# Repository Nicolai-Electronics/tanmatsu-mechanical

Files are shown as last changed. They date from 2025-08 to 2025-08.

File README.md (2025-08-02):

# Tanmatsu mechanical design files

This repository contains the design files for the 3D printed mechanical parts for the Tanmatsu.

These consist of the following: 
  * Case
  * Spacer 
  * Speaker adapter 

All parts are integrated in the FreeCAD design file. Also a separate
STEP file each part, so people can print these directly from this
repository.

In order to add the bolts to the design, install the 'Fasteners' workbench 
via the add-on manager. 

# Which revision do I need?

You can find out your mainboard revision by going to `Settings > Device
information` in the launcher firmware.

If you have board revision 1 or 2 you need the "for revision 2" files. If you
have a newer board revision you need the "for revision 3" files.

The breaking change in case design is due to us having to move the audio jack
down by two millimeters and outwards by two millimeters to solve a
manufacturing problem.

# Getting Tanmatsu STEP files.

Clone the repositories for both the Tanmatsu mainboard and a frontpanel. 

 * Open the design wiht KiCAD.
 * Open the PCB editor.
 * Select Export -> "STEP / GLB/, etc."
 * Select STEP as format. 
 * Use the default settings
 * Press Export. 
 * Now import the STEP files in the FreeCAD file. Make sure to disable the
   'Linkgroup' setting while importing. Otherwise deleting the PCB will become
   very tiresome. 
 * Place them in the correct location by selecting the corresponding PCB and:
    * Tanmatsu PCB: set Data -> Placement -> Position -> z = -1.55 mm
    * Frontpanel PCB: set Data -> Placement -> Position -> z = 2.40 mm

# Generating output files

Generating the output files from FreeCAD happens via a bash script command line
form. With FreeCAD close and from the repository root directory execute
`./tools/export_manufacturing_files.sh`. The resulting STEP and AMF files will 
appear in the `./release/` directory with the correct names. 

The 'tools' directory has a simple FreeCAD file available for testing purposes.
Exporting everything while debugging Python scripts get boring real fast.

Note: The script does produce some errors from the Fasteners Workbench. 
See this issue: https://github.com/shaise/FreeCAD_FastenersWB/issues/454

# License

Copyright 2024-2025 Nicolai Electronics

Copyright 2024-2025 Ytec Engineering

Copyright 2025 Jelle Haandrikman

This work is licensed under the CERN-OHL-P license. Full license text is
included in the [LICENSE](LICENSE) file.

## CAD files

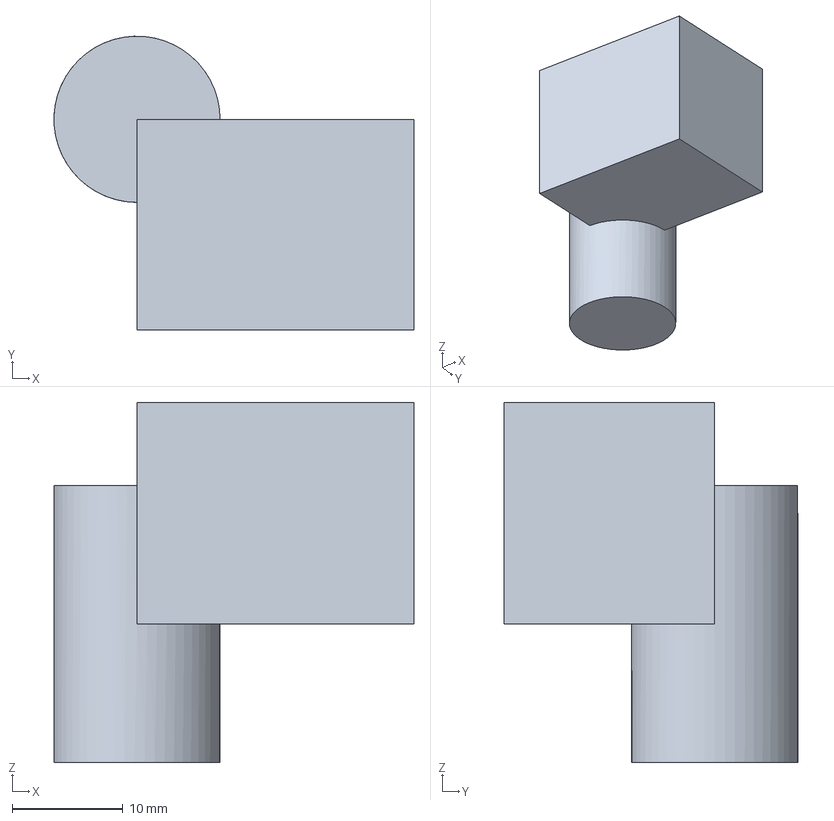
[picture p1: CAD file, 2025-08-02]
tools/test_freecad_file.FCStd
32.5 x 26.5 x 32.5 mm

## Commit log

2025-05-04 Remove overhanging catch for battery box, rename STL files
    [assembly.scad, assembly_internal_antenna.stl, assembly_nosma.stl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]
2025-06-12 First setup with FreeCAD design files.
    [Tanmatsu_3D-printed-case.step, Tanmatsu_3D-printed-spacer.step, assembly_internal_antenna.stl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]
2025-06-12 Getting everything set up.
    * Updated README.md with info on how to get STEP files from PCB.
    * Added STEP files from frontpanel and Tanmatsu mainboard.
    * Tanmatsu mainboard now has the USB-A connector.
2025-06-12 FreeCAD model for speaker_adapter added.
    [speaker_adapter-speaker_adapter.step, speaker_adapter.FCStd]
2025-06-12 Case: added studs near screw holes.
    [Tanmatsu_3D-printed-case.step, speaker_adapter.FCStd]
2025-06-12 Speaker now has correct length and added AMF files.
    [Tanmatsu_3D-printed-case.amf, Tanmatsu_3D-printed-spacer.amf, speaker_adapter-speaker_adapter.amf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]
2025-06-12 Case has connectors and speaker adapter included
    Case now has room for all external connectors
    SNAFU with asymetrical mounting holes fixed.
    Speaker adapter now included.
    Keycord holes now more robust extruded.
    [Tanmatsu_3D-printed-case.amf, Tanmatsu_3D-printed-case.step, speaker_adapter.FCStd]
2025-06-12 Fix changes from yesterday evening.
    Added original STL assembly for easier comparing sizes.
    Made battery compartment less tall and now doesn't bump into diodes.
    Notches for holding PCB at upper side now also have clearance for PCB.
    [Tanmatsu_3D-printed-case.amf, Tanmatsu_3D-printed-case.step, Tanmatsu_3D-printed-speaker_adapter.amf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]
2025-06-12 Small changes for ergonomics and older tanmatsu mic location.
    [Tanmatsu_3D-printed-case.amf, Tanmatsu_3D-printed-case_field_test.amf]
2025-06-12 Increased wall thickness for ergonomics for real.
    [Tanmatsu_3D-printed-case.amf, Tanmatsu_3D-printed-case_field_test.amf]
2025-06-12 Chamfers, fillets and thingies OK now.
    [Tanmatsu_3D-printed-case.amf, Tanmatsu_3D-printed-case_field_test.amf]
2025-06-12 Proto version for production
    Refactored Case build-up
    Speaker case size the same as speaker adapter
    Lower edges to 24 mm.
    Audio connector protection attached to case and spacer.
    Edges have now fillets
    [Tanmatsu_3D-printed-case.amf, Tanmatsu_3D-printed-case.step, Tanmatsu_3D-printed-case_field_test.amf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]
2025-06-12 Remove separate speaker adapter design file.
    [speaker_adapter-speaker_adapter.amf, speaker_adapter-speaker_adapter.step, speaker_adapter.FCStd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]
2025-06-12 Solved review comments according to 'issues.txt'.
    [Tanmatsu_3D-printed-case.amf, Tanmatsu_3D-printed-case.step, Tanmatsu_3D-printed-spacer.amf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]
2025-06-12 First Of A kind Updates to Case and Spacer
    Audio connector protection has more space for audio connnector.
    Audio connector protection better fit.
    Ergonic grip now has better fit, renders and mirror now works.
    CATT connector has ridges on case and spacer.
    Refactored dependencies for keyholes.
    Spacer for field test models added.
    [Tanmatsu_3D-printed-case.amf, Tanmatsu_3D-printed-case.step, Tanmatsu_3D-printed-case_field_test.amf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]
2025-06-12 Field Test adapter and spacer now fit nicely around audio connector.
    Removed issues file with review input from Renze.
    Coordinates of field test case now in line with original case.
    [Tanmatsu_3D-printed-case_field_test.amf, Tanmatsu_3D-printed-case_field_test.step, Tanmatsu_3D-printed-spacer_field_test.amf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]
2025-06-12 New audio protector case.
2025-06-12 Fix for audio connector protection.
    [Tanmatsu_3D-printed-case.amf, Tanmatsu_3D-printed-case.step, Tanmatsu_3D-printed-spacer.amf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]
2025-06-12 Added space for middle bottom nut in spacer.
    Further:
    Field Test case and spacer cleaned up.
    Moved OpenSCAD STL for case to it's own folder.
    [Tanmatsu_3D-printed-case.amf, Tanmatsu_3D-printed-case.step, Tanmatsu_3D-printed-case_field_test.amf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]
2025-06-20 Fixed speaker container size and updated Tanmatsu PCB.
    [Tanmatsu_3D-printed-case.amf, Tanmatsu_3D-printed-case.step, Tanmatsu_3D-printed-case_field_test.amf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]
2025-06-21 Now properly fixed the speaker adapter dimensions.
    [Tanmatsu_3D-printed-case.amf, Tanmatsu_3D-printed-case.step, Tanmatsu_3D-printed-case_field_test.amf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]
2025-06-22 Screw heads in case now have the correct height.
    Refactored screw heads and screw head support for thecase to a single sketch.
    [Tanmatsu_3D-printed-case.amf, Tanmatsu_3D-printed-case.step, Tanmatsu_3D-printed-case_field_test.amf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]
2025-06-22 Now exported 3D manufacturing files with all the details.
    [Tanmatsu_3D-printed-case.amf, Tanmatsu_3D-printed-case.step, Tanmatsu_3D-printed-case_field_test.amf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]
2025-07-09 Remove release files from repository
    [Tanmatsu_3D-printed-case.amf, Tanmatsu_3D-printed-case.step, Tanmatsu_3D-printed-field_test_case.amf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]
2025-07-26 Cleaned up design.
    Less manual chamfers.
    Rounded corners at the top go from 4.0 mm. radius to 5.0 mm radius.
    Combined Fillet and Chamfers for nice rounded corners at the top on
    bottom side.
2025-08-02 Generate STEP and AMF files from command line.
    * Added as shell script and Python script to generate the STEP and AMF
    files for the mechanical parts of the Tanmatsu.
    * Added a small sample FreeCAD file to speed up debugging of the Python
    script.
    * Updated README and .gitignore to reflect these changes.
    [test_freecad_file.FCStd]
2026-04-17 Add pocket for infrared LED
2026-10-27 Cleanup, add add-on version of case, add camera version of case, add extra cutout to infrared LED wall to avoid collision with USB hub chip
2026-10-27 Fix normal case design and add local export script
